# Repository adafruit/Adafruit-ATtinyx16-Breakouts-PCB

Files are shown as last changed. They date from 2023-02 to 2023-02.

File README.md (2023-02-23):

## Adafruit ATtinyx16 Breakouts with seesaw - STEMMA QT / Qwiic PCB

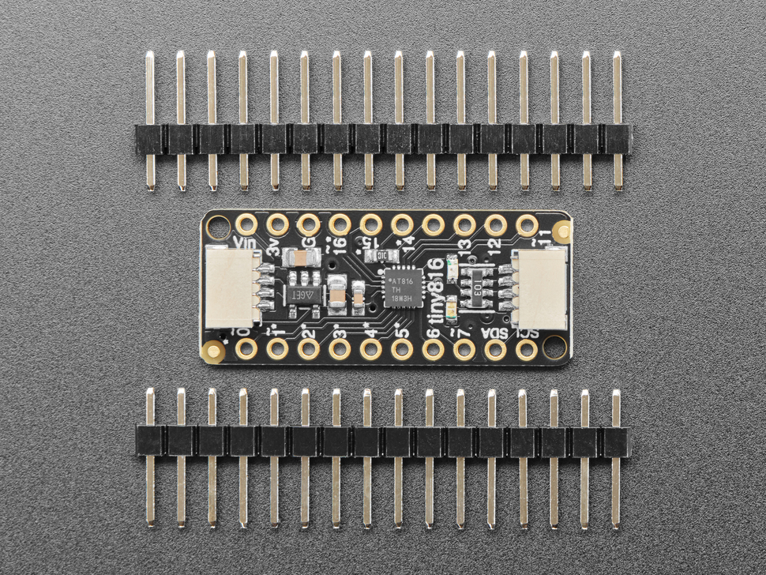
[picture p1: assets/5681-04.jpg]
<a href="http://www.adafruit.com/products/5681"><br/>
Click here to purchase one from the Adafruit shop</a>
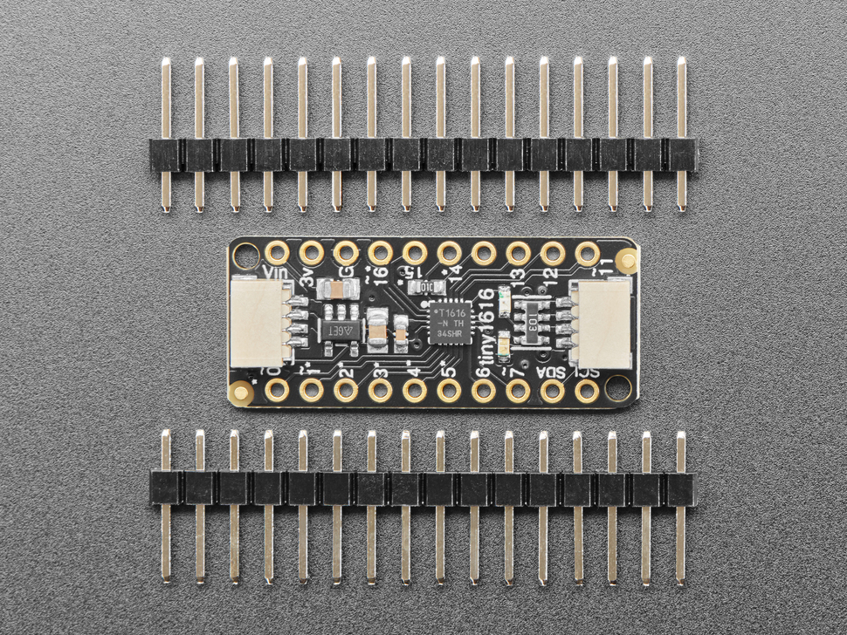
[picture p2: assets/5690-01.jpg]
<a href="http://www.adafruit.com/products/5690"><br/>
Click here to purchase one from the Adafruit shop</a>

PCB files for the Adafruit ATtiny816 and ATtiny1616 Breakouts with seesaw - STEMMA QT / Qwiic. 

Format is EagleCAD schematic and board layout
* https://www.adafruit.com/product/5681
* https://www.adafruit.com/product/5690

### Description

These breakout boards are a "three in one" product:

* The ATtinyx16 are part of the 'next gen' of AVR microcontrollers, and now we have cute development/breakout boards for them, with just enough hardware to get the chip up and running.
* It's also an Adafruit seesaw board. Adafruit seesaw is a near-universal converter framework which allows you to add and extend hardware support to any I2C-capable microcontroller or microcomputer. Instead of getting separate I2C GPIO expanders, ADCs, PWM drivers, etc, seesaw can be configured to give a wide range of capabilities.
* Finally, with STEMMA QT connectors on it, you could use it as either an I2C controller or peripheral with plug-and play support.

We primarily designed this board for our own use: it's a mini dev board that lets us design with the ATtiny816 just like we did for the ATSAMD09. With the 2021-2022 silicon shortage, we're adapting some of our SAMD09 designs to the ATTiny8xx series and wanted a quick minimal board to test code on.

Each breakout comes with the assembled and tested board, as well as some header strips. Each PCB is fairly minimal and contains:

The ATtiny816 and ATtiny1616 are identical in specifications except for storage space: 
* The ATtiny816 has 8KB flash, 512 bytes of RAM, 128 bytes of EEPROM
* The ATtiny1616 has 16KB flash, 2KB of RAM, 256 bytes of EEPROM

* Internal oscillator can run up to 20MHz
* Internal hardware multiplier
* Can run from 2V to 5V power/logic (check the datasheet for max speed at desired power)
* 3.3V regulator - by default we run at the Vin voltage, which can be 5V, but there's a solder jumper on the bottom if you'd like to select 3V logic.
* Green power LED
* Red indicator LED
* Two STEMMA QT I2C connectors with 10K pullup resistors, connected to pins 8 and 9

These boards comes pre-programmed with seesaw peripheral code that will let it act as an "I2C to something" converter, basically a little I2C-controlled friend to do all the timing-sensitive things many microcontrollers and microcomputers are not good at.

For example, using these breakouts with the pre-burned seesaw firmware gives you

* 12 x GPIO with selectable pullup resistors: 0-5, 6, 8, 11, 14, 15, 16
* 9 x 10-bit ADC inputs - pins 0, 1, 2, 3, 4, 5, 14, 15, 16
* 5 x 8-bit PWM outputs - pins 0, 1, 7, 11, 16
* 1 x NeoPixel output (up to 60 pixels)
* 1 x EEPROM with 127 byte of NVM memory (handy for storing small access tokens or MAC addresses) - last byte of EEPROM is used for I2C address selection
* 1 x Interrupt output that can be triggered by any of the accessories - pin 6
* 2 x I2C address selection pins - pins 12 and 13
* 1 x Activity LED on pin 10, tied active low

Of course, you can configure or reprogram the chip to however you want to use it - we like using SpenceKonde's megaTinyCore which brings Arduino peripheral support to this series of chips. To program the chip you will need a 'UPDI' programmer, which you can make with a USB-to-Serial cable and a single 4.7K or 10K resistor.

Please note: The boards do not come with a bootloader. If you want to do development on seesaw (e.g. changing the configuration) you need a separate UPDI programming setup! The firmware we put on is available as this example sketch, compiled using the megaTinyCore. We don't provide any support for custom builds of seesaw - we think this is cool and useful for the Maker community!

For more details including the documentation on how to use seesaw, libraries for Arduino/CircuitPython/Raspberry Pi Python, schematics, and more check out the Adafruit seesaw guide

### License

Adafruit invests time and resources providing this open source design, please support Adafruit and open-source hardware by purchasing products from [Adafruit](https://www.adafruit.com)!

Designed by Limor Fried/Ladyada for Adafruit Industries.

Creative Commons Attribution/Share-Alike, all text above must be included in any redistribution. 
See license.txt for additional details.

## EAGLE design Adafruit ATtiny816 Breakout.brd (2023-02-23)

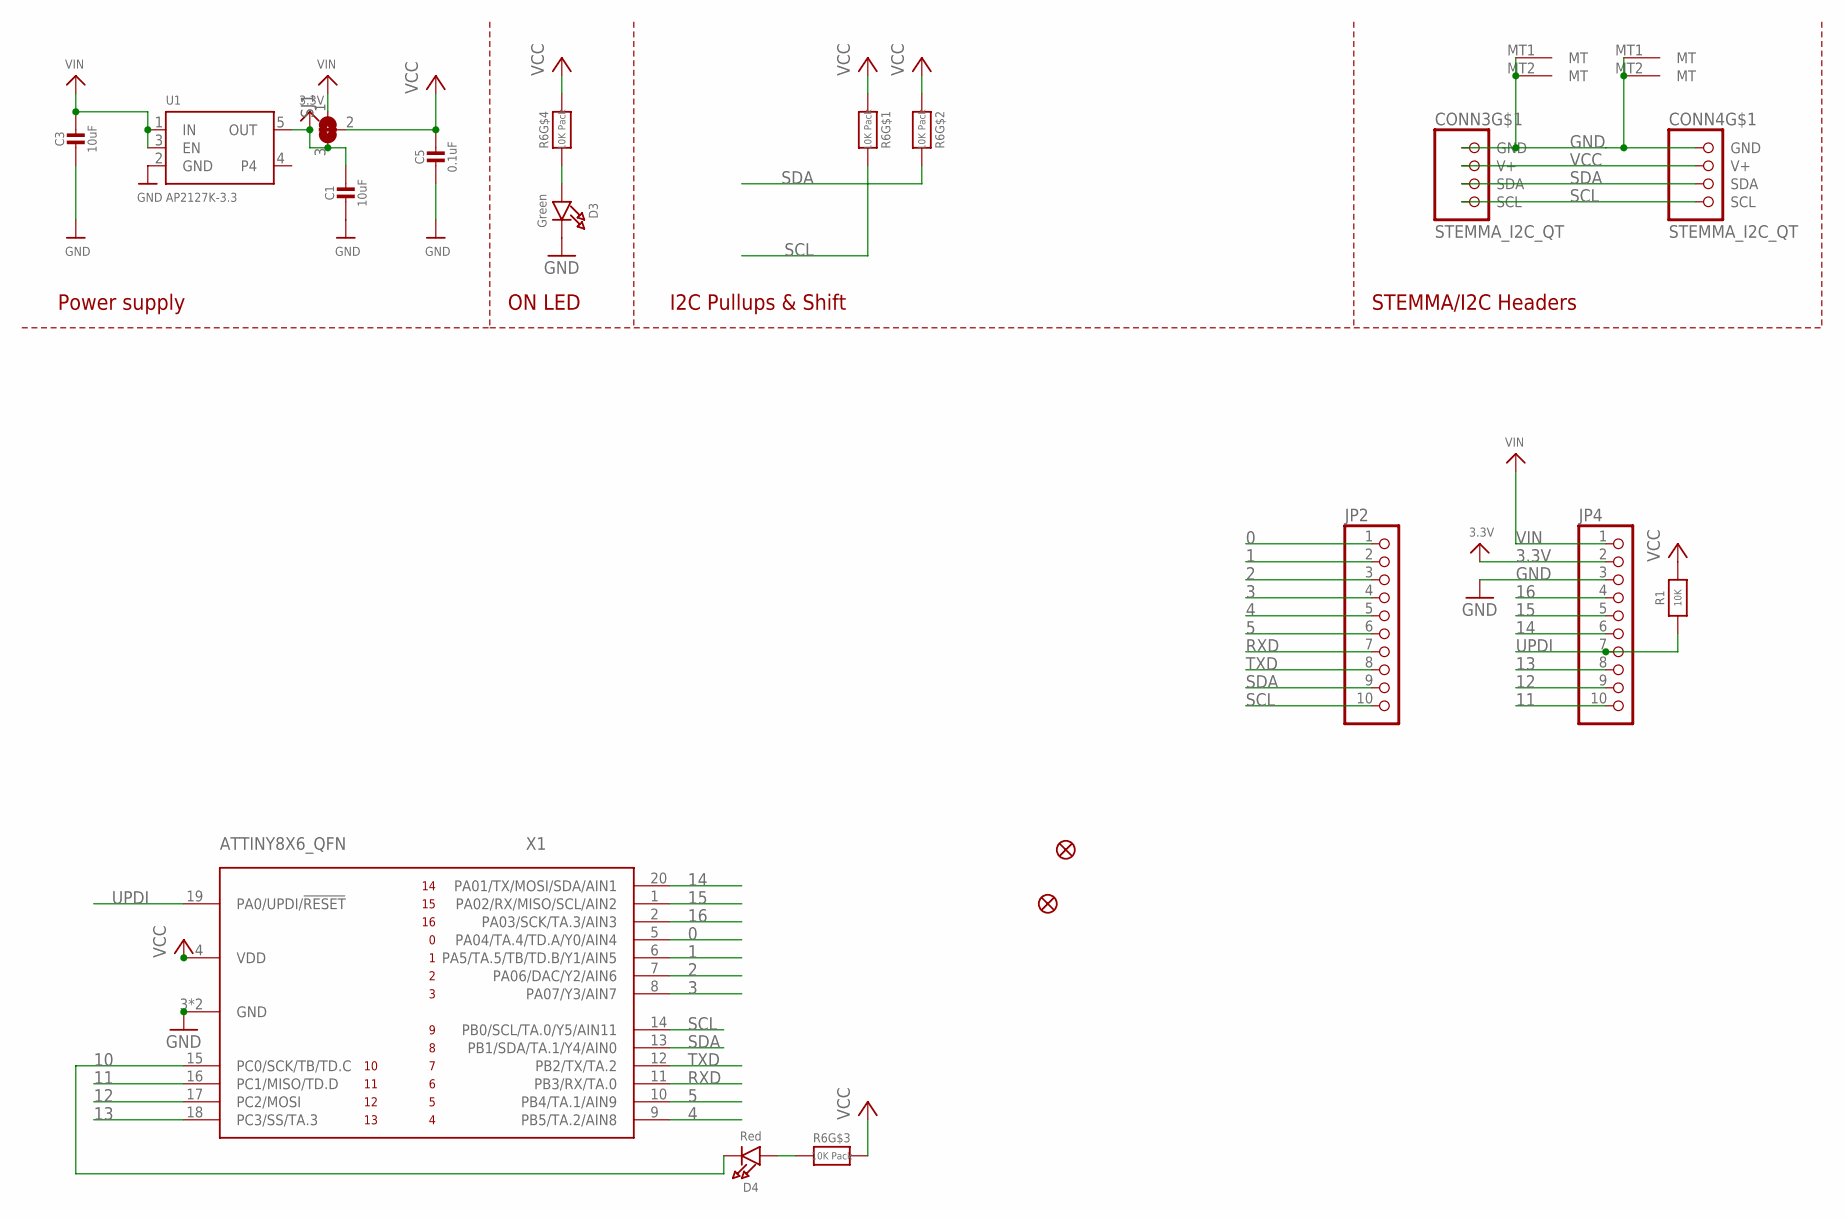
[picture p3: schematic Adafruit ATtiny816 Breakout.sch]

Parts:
C1: 10uF; 0805_10MGAP
C3: 10uF; 0805-NO
C5: 0.1uF; 0603-NO
CONN3, CONN4: STEMMA_I2C_QT; JST_SH4
D3: Green; CHIPLED_0603_NOOUTLINE
D4: Red; CHIPLED_0603_NOOUTLINE
FID1, FID2: FIDUCIAL_1MM
JP2, JP4: HEADER-1X1070MIL; 1X10_ROUND70
R1: 10K; 0603-NO
R6: 10K Pack; RESPACK_4X0603
SJ1: SOLDERJUMPER_2WAY; SOLDERJUMPER_2WAY_OPEN_NOPASTE
U1: AP2127K-3.3; SOT23-5
X1: ATTINY8X6_QFN; QFN20_3MM

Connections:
0: JP2.1, X1.5 (PA04/TA.4/TD.A/Y0/AIN4)
1: JP2.2, X1.6 (PA5/TA.5/TB/TD.B/Y1/AIN5)
2: JP2.3, X1.7 (PA06/DAC/Y2/AIN6)
3: JP2.4, X1.8 (PA07/Y3/AIN7)
3.3V: C1.1, JP4.2, SJ1.3, U1.5 (OUT)
4: JP2.5, X1.9 (PB5/TA.2/AIN8)
5: JP2.6, X1.10 (PB4/TA.1/AIN9)
10: D4.C, X1.15 (PC0/SCK/TB/TD.C)
11: JP4.10, X1.16 (PC1/MISO/TD.D)
12: JP4.9, X1.17 (PC2/MOSI)
13: JP4.8, X1.18 (PC3/SS/TA.3)
14: JP4.6, X1.20 (PA01/TX/MOSI/SDA/AIN1)
15: JP4.5, X1.1 (PA02/RX/MISO/SCL/AIN2)
16: JP4.4, X1.2 (PA03/SCK/TA.3/AIN3)
GND: C1.2, C3.2, C5.2, CONN3.1 (GND), CONN3.MT1 (MT), CONN3.MT2 (MT), CONN4.1 (GND), CONN4.MT1 (MT), CONN4.MT2 (MT), D3.C, JP4.3, U1.2 (GND), X1.3 (GND), X1.PAD (GND)
unnamed: D3.A, R6.4 (1)
unnamed: D4.A, R6.3 (1)
RXD: JP2.7, X1.11 (PB3/RX/TA.0)
SCL: CONN3.4 (SCL), CONN4.4 (SCL), JP2.10, R6.8 (2), X1.14 (PB0/SCL/TA.0/Y5/AIN11)
SDA: CONN3.3 (SDA), CONN4.3 (SDA), JP2.9, R6.7 (2), X1.13 (PB1/SDA/TA.1/Y4/AIN0)
TXD: JP2.8, X1.12 (PB2/TX/TA.2)
UPDI: JP4.7, R1.1, X1.19 (PA0/UPDI/!RESET)
VCC: C5.1, CONN3.2 (V+), CONN4.2 (V+), R1.2, R6.1, R6.2 (1), R6.5 (2), R6.6 (2), SJ1.2, X1.4 (VDD)
VIN: C3.1, JP4.1, SJ1.1, U1.1 (IN), U1.3 (EN)

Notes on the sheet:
I2C Pullups & Shift
STEMMA/I2C Headers
ON LED
Power supply

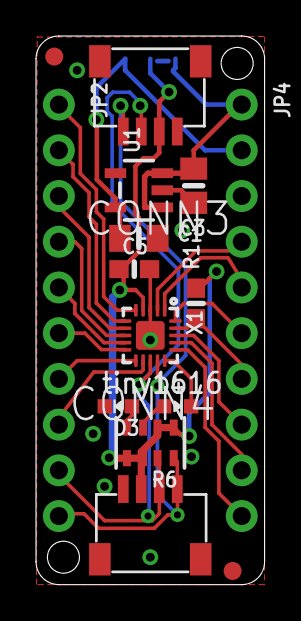
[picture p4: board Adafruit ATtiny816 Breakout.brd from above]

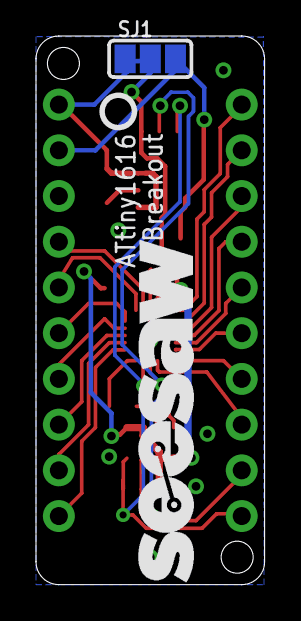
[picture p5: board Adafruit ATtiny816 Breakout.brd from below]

Board: 2 copper layers, 12.7 x 30.5 mm, 75 parts (27 on the bottom side), 24 nets.

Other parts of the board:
PLABEL0: PLABEL0
PLABEL1: PLABEL1
PLABEL2: PLABEL2
PLABEL3: PLABEL3
PLABEL4: PLABEL4
PLABEL5: PLABEL5
PLABEL6: PLABEL6
PLABEL7: PLABEL7
PLABEL8: PLABEL8
PLABEL9: PLABEL9
PLABEL10: PLABEL10
PLABEL11: PLABEL11
PLABEL12: PLABEL12
PLABEL13: PLABEL13
PLABEL14: PLABEL14
PLABEL15: PLABEL15
PLABEL17: PLABEL17
PLABEL18: PLABEL18
PLABEL19: PLABEL19
PLABEL20: PLABEL20
PLABEL21: PLABEL21
PLABEL22: PLABEL22
PLABEL23: PLABEL23
PLABEL24: PLABEL24
PLABEL25: PLABEL25
PLABEL26: PLABEL26
PLABEL27: PLABEL27
PLABEL28: PLABEL28
PLABEL29: PLABEL29
PLABEL30: PLABEL30
PLABEL31: PLABEL31
PLABEL32: PLABEL32
PLABEL33: PLABEL33
PLABEL35: PLABEL35
PLABEL36: PLABEL36
PLABEL37: PLABEL37
PLABEL38: PLABEL38
PLABEL39: PLABEL39
PLABEL40: PLABEL40
PLABEL41: PLABEL41
PLABEL42: PLABEL42
PLABEL43: PLABEL43
PLABEL44: PLABEL44
PLABEL45: PLABEL45
PLABEL46: PLABEL46
PLABEL47: PLABEL47
PLABEL48: PLABEL48
PLABEL49: PLABEL49
PLABEL50: PLABEL50
PLABEL51: PLABEL51
PLABEL52: PLABEL52
PLABEL53: PLABEL53
PLABEL54: PLABEL54
PLABEL55: PLABEL55
PLABEL56: PLABEL56
PLABEL57: PLABEL57
PLABEL58: PLABEL58
U$7: SEESAW_LOGO
U$12: PCBFEAT-REV-040

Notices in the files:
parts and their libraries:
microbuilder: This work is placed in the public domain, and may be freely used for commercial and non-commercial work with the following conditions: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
